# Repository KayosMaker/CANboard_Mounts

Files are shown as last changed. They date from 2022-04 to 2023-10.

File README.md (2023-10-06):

# Mounting Solutions for Nema 14 Based CANbus Toolhead Boards
Files are available to support the following boards:
* BTT EBB36 CAN v1.0
* BTT EBB36 CAN v1.1
* BTT EBB36 CAN v1.2
* Mellow FLY SHT-36
* Mellow FLY SHT-36 2.0

The EBB36 1.0 had rear facing buttons that necessitated a more complicated mount to retain functionality.  Those mounts are in a dedicated folder.  (Note: I won't be updating the mounts for this board to include additional extruders, since it has been superceded by v1.1 and v1.2)  

The EBB36 v1.1, EBB36 v1.2, Mellow Fly SHT-36, and Mellow FLY SHT-36 v2.0 all use the same set of mounts.  They are in a dedicated folder.

## Extruder Compatibility
Since each extruder using a NEMA 14 seems to use it's own unique motor orientation, I created this set of mounts to cover most common setups.  These mounts allow the board to be oriented properly with the umbilical strain relief pointing up, despite the different motor orientations.  If there's a common extruder with a different motor orientation that I missed, just message me on Discord or open an issue here on Git to let me know.  The current files align with the motor orientations of the following extruders: 
* Sherpa Mini
* Sherpa Micro
* LGX Lite
* Sailfin (OG Sailfin as well as my silly Sharkfin mod)
* Orbiter v1.5
* Orbiter v2.0
* VZHextrudort High
* VZHextrudort Low
* VZHextrudort CNC
* Galileo 2 Standalone(works with Orbiter v2 mounts)
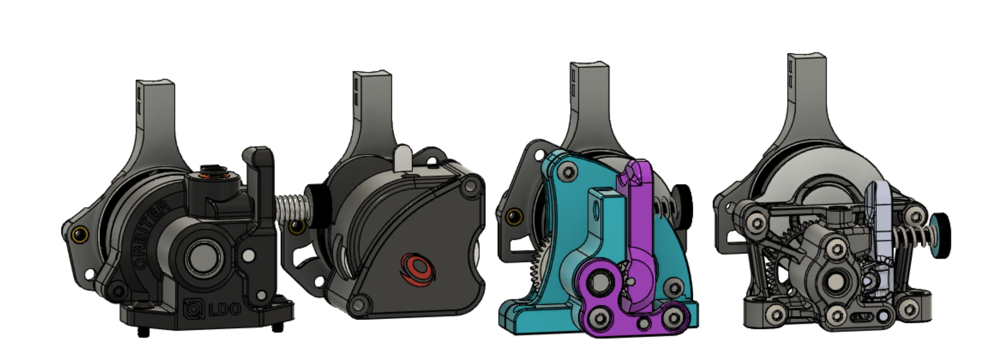
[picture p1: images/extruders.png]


## Plate Types
There are 3 types of plates available: plain, strain relief, and overmold strain relief.  Each has a dedicated folder for the related stls.  The basic strain relief is for most diy cables.  The overmold strain relief is for retail cables available from Molex.  The plain brackets are for printers that have their own solution for umbilical or cable chains. 

Mellow has moved to a new dual plug setup on the FLY SHT-36 2.0, negating the use of the overmold brackets.  Stick with the regular strain relief versions for that board.

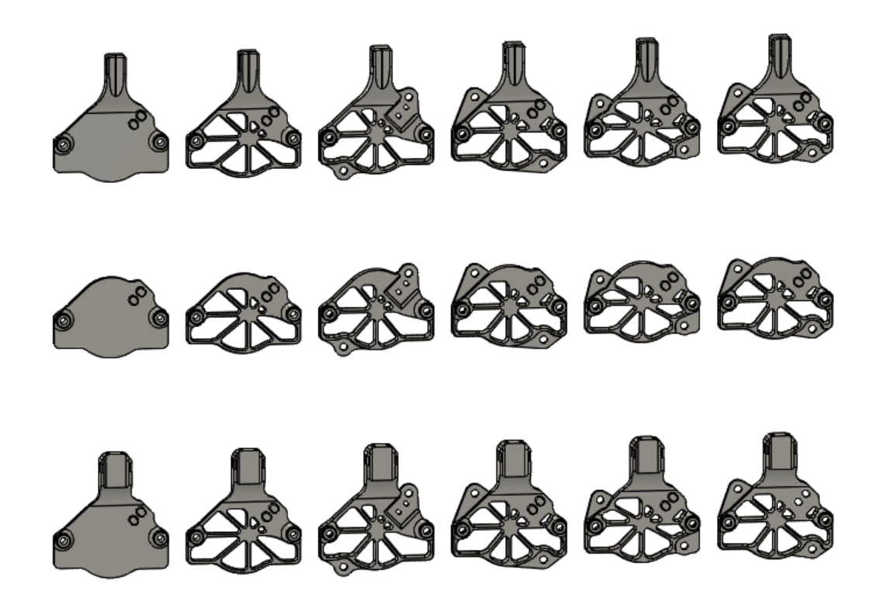
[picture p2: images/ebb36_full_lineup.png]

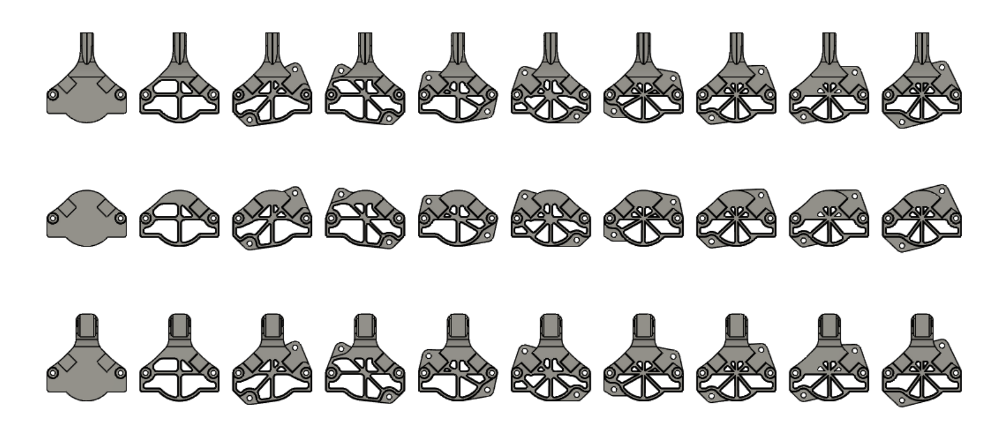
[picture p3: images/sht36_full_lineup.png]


## Usage Notes
The output for the stepper can be switched to the other side of the board if the user wants it so.  The bracket base geometries have clearance for that in regular and mirrored orientations.  Not all extruder motor orientations allow this, but some do.
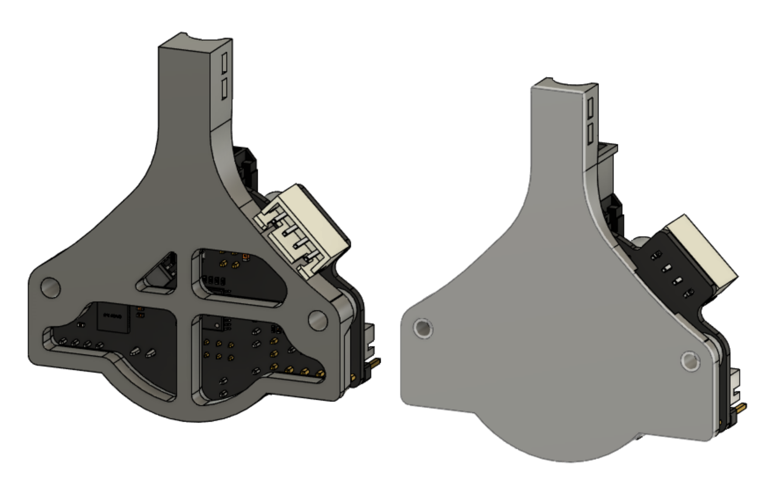
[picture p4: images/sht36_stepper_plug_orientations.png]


These plates are meant to work with printed mounting posts as spacers.  The extruder motor gets mounted with screws that are 5mm longer than called for(so they protrude from the back of the motor mounting ears).  Each end of the printed standoff post gets an M3 heatset insert.  Mounting post length should be chosen based on the motor you are using.  Measure the distance from the back of the motor to the back side of the mounting ears.  Add .5-1mm so the board mount isnt touching the motor, and print the corresponding post length from the folder.  The post is screwed onto the protruding motor mounting screw, and then the mounting bracket is screwed into the mounting posts.  Then you mount the board on the bracket.  The brackets with different board and motor screw orientations will require heatsets in the bracket, to mount the board. 

There are 3 styles of standoff posts available.  They print in the orientation shown.  The classic round ones are fine as long as you print hot enough that layer adhesion is strong.  Geometry is in place to allow the internal overhang to print easily.  If that makes you uneasy, choose the octagonal or teardrop shapes and print them lying down as shown.  
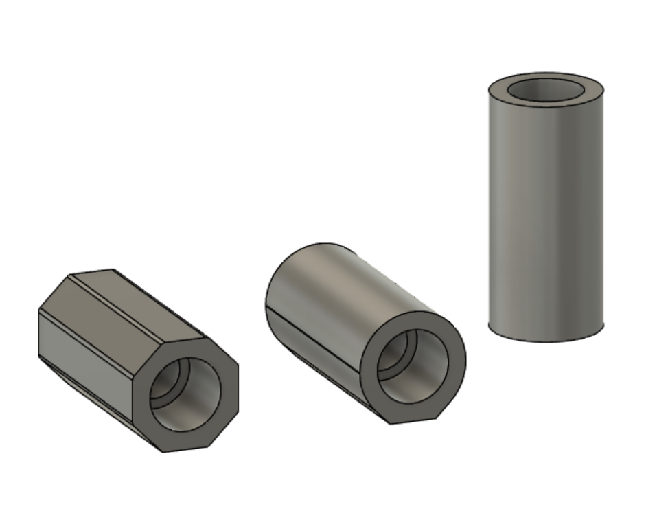
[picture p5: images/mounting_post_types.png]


## Usermods
Mod|Description|Link
|:--------:|:-------------------------:|:---:|
Reapola's Galileo Mounts|Mounts for rear or side of Galileo, with CAD|https://github.com/KayosMaker/CANboard_Mounts/tree/main/Usermods/Reapola/Galileo%20Mount%20for%20SHT36
K78L12-500R3 Mounts|Mounts with K78L12-500R3 included, with CAD|https://github.com/KayosMaker/CANboard_Mounts/tree/main/Usermods/mk-maddin/K78l12-500R3_24-12V_mount

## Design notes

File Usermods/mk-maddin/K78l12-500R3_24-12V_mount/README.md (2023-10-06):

# Description
This mod additionally mounts the 24V-12V [K78L12-500R3](https://www.digikey.com/en/products/detail/mornsun-america-llc/K78L12-500R3/16784476) buck converter.
This is helpful when using e.g. 12V fans like Delta BFB0412HHA-A (12V) on your toolhead.

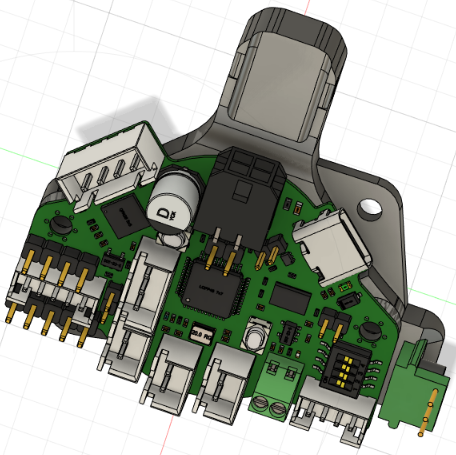
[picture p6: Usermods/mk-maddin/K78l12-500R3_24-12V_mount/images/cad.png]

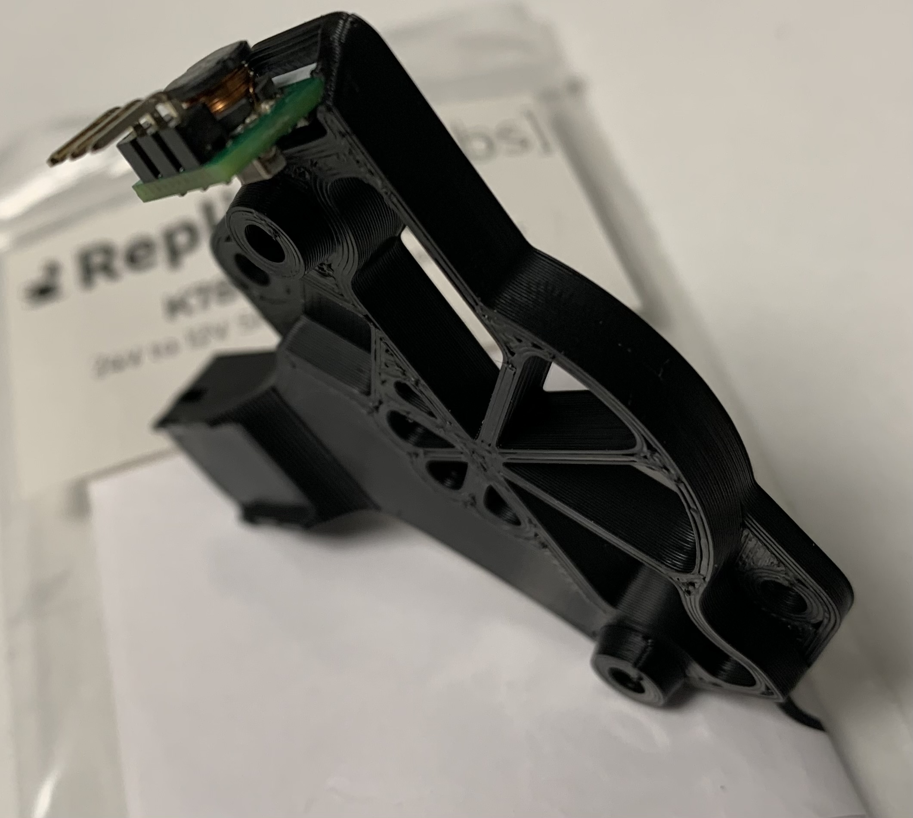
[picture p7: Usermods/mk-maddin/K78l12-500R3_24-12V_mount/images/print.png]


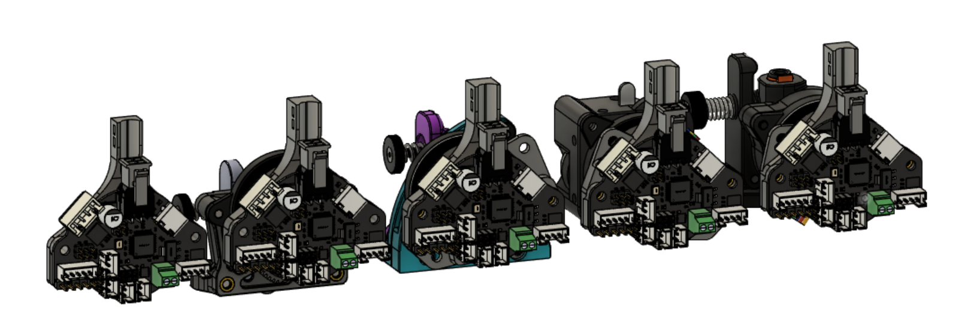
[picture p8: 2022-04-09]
images/sht36_lineup_w_boards.png

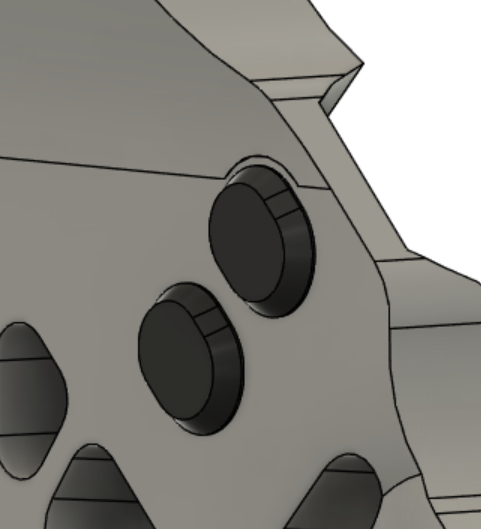
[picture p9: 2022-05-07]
images/ebb36_buttons_front.png

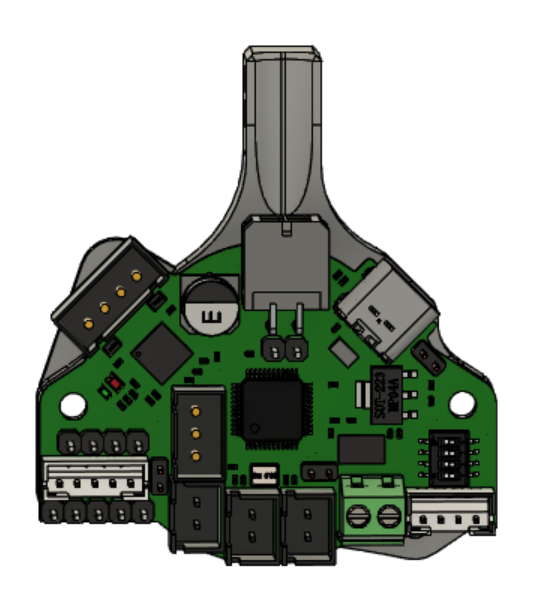
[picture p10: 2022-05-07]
images/ebb36_bracket.png

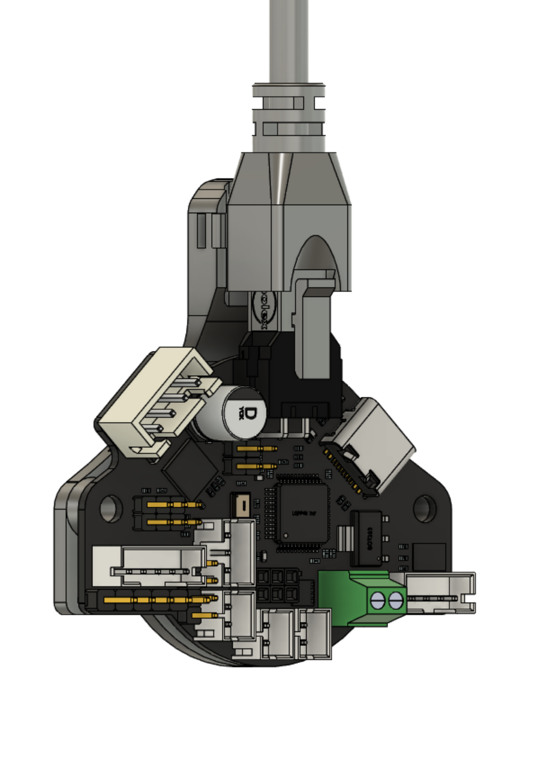
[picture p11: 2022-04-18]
images/overmolded_strain_relief.png

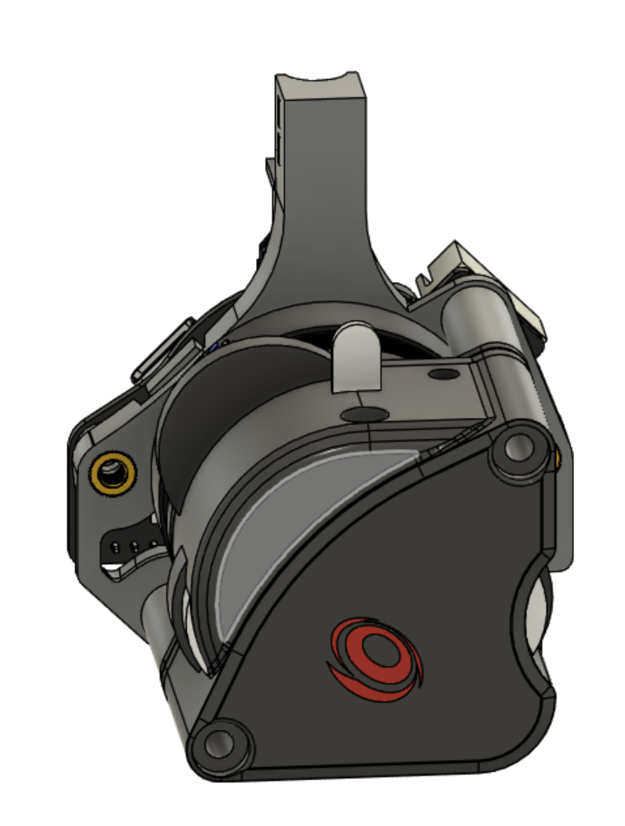
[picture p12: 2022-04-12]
images/sht36_complete_front.png

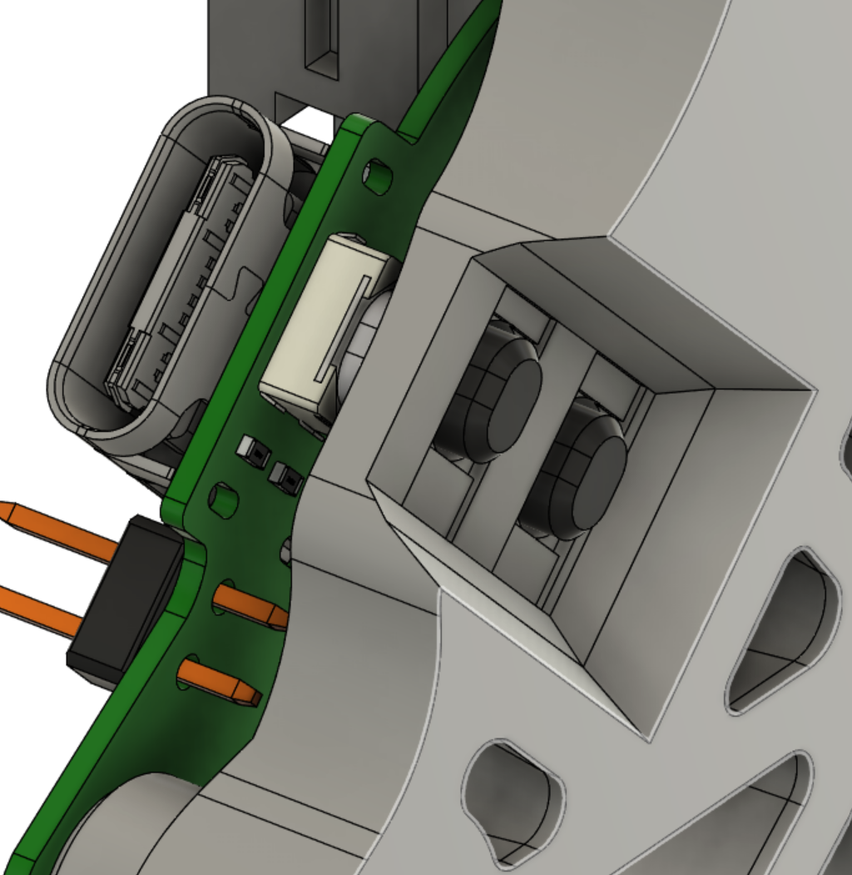
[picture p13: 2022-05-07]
images/ebb36_buttons_rear.png

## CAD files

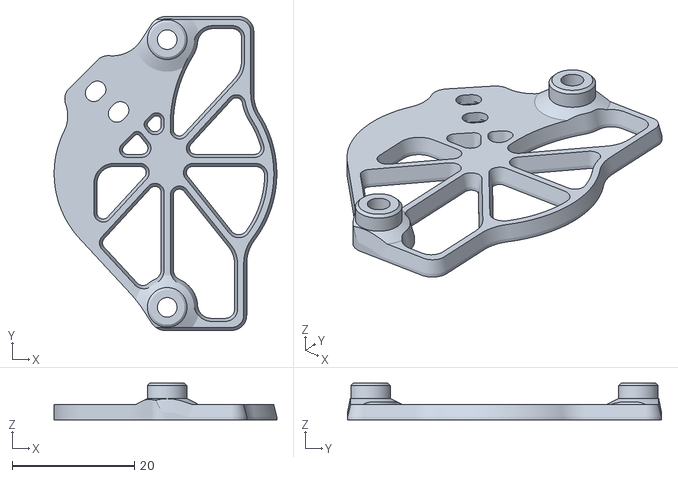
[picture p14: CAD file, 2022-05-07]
STLs/BTT_EBB36_1.0_Mounts/BTT_EBB36_1.0_mounts_plain/EBB36 1.0 sherpa mini mount.stl
36.5 x 51.4 x 6.00

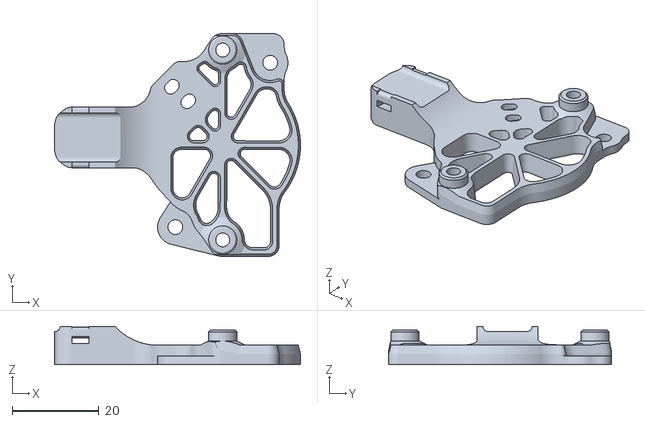
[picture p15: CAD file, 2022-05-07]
STLs/BTT_EBB36_1.0_Mounts/BTT_EBB36_1.0_mounts_with_overmold_strain_relief/EBB36 1.0 orbiter 2.0 mount overmold strain relief.stl
56.8 x 51.4 x 8.86

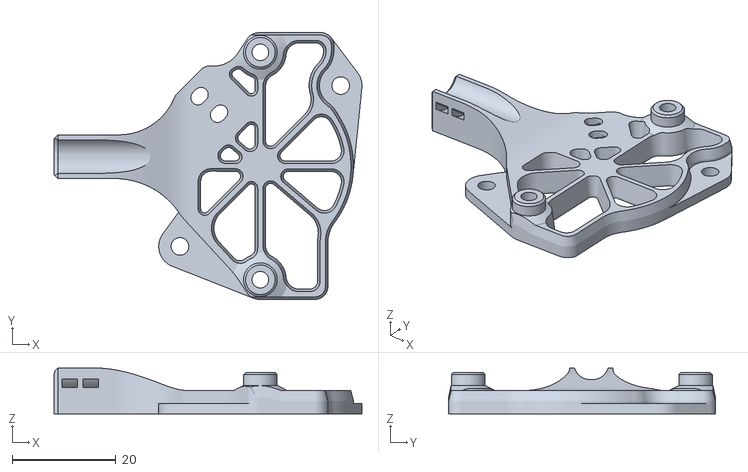
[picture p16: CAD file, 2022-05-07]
STLs/BTT_EBB36_1.0_Mounts/BTT_EBB36_1.0_mounts_with_strain_relief/EBB36 1.0 lgx lite mount strain relief.stl
59.4 x 51.4 x 8.86

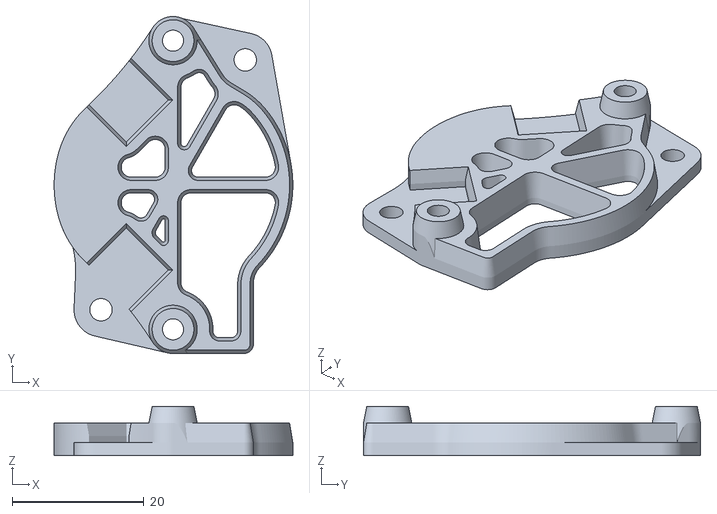
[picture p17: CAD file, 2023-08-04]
STLs/Mellow_SHT36_BTT_EBB36_1.1_1.2_Mounts/Mellow_SHT36_and_BTT_EBB36_1.1_1.2_mounts_plain/STH-36_and_BTT_EBB36_1.1_1.2_orbiter_2.0_mounting_plate.stl
36.3 x 51.2 x 7.50

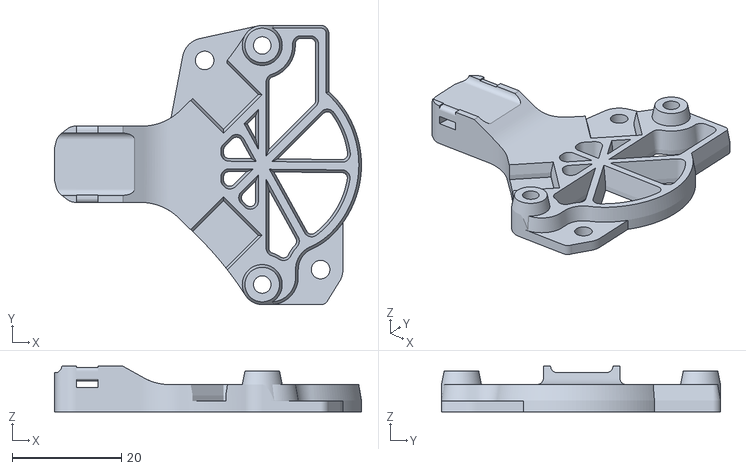
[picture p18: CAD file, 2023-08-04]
STLs/Mellow_SHT36_BTT_EBB36_1.1_1.2_Mounts/Mellow_SHT36_and_BTT_EBB36_1.1_1.2_mounts_with_overmold_strain_relief/SHT-36_and_BTT_EBB3_vzhextrudort_high_mounting_plate_overmold_strain.stl
56.3 x 51.2 x 8.36

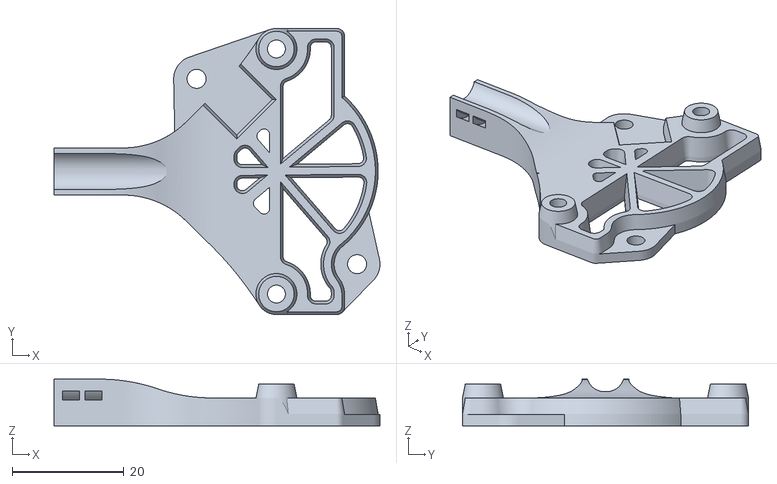
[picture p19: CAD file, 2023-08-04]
STLs/Mellow_SHT36_BTT_EBB36_1.1_1.2_Mounts/Mellow_SHT36_and_BTT_EBB36_1.1_1.2_mounts_with_strain_relief/SHT-36_and_BTT_EBB36_1.1_1.2_vzhextrudort_cnc_mounting_plate_strain_relief.stl
58.3 x 51.2 x 8.36

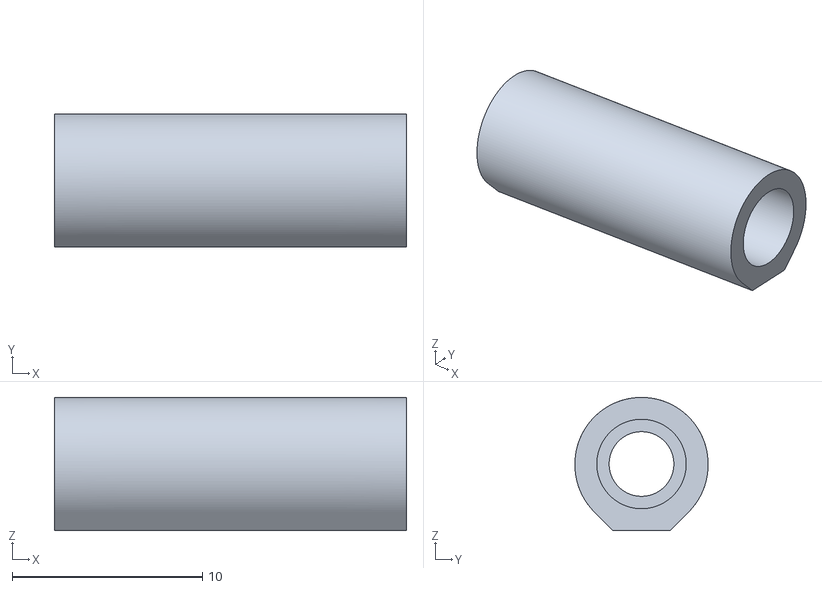
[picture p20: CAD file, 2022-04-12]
STLs/motor_standoff_posts/18.5mm_teardrop_universal_spacer.stl
18.5 x 7.00 x 7.00

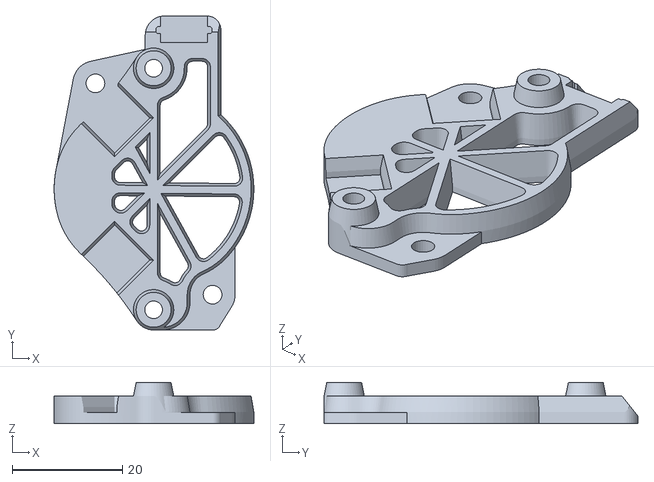
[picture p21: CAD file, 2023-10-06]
Usermods/mk-maddin/K78l12-500R3_24-12V_mount/STL/Mellow_SHT36_BTT_EBB36_1.1_1.2_Mount/Mellow_SHT36_and_BTT_EBB36_1.1_1.2_mounts_plain/SHT-36_vzhextrudort_high_mounting_plate_K78l12-500R3.stl
36.3 x 57.0 x 7.50

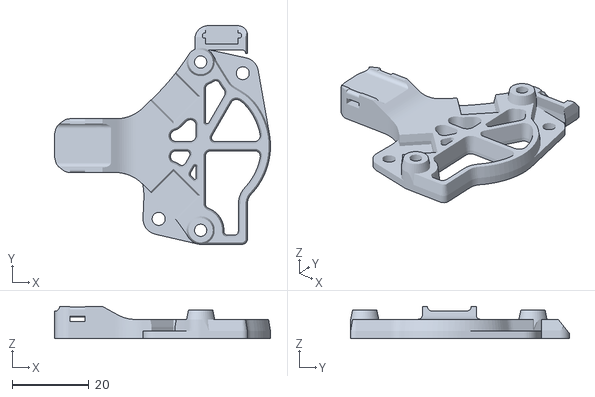
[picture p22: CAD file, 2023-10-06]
Usermods/mk-maddin/K78l12-500R3_24-12V_mount/STL/Mellow_SHT36_BTT_EBB36_1.1_1.2_Mount/Mellow_SHT36_and_BTT_EBB36_1.1_1.2_mounts_with_overmold_strain_relief/STH-36_orbiter_2.0_mounting_plate_overmold_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
56.3 x 57.0 x 8.36

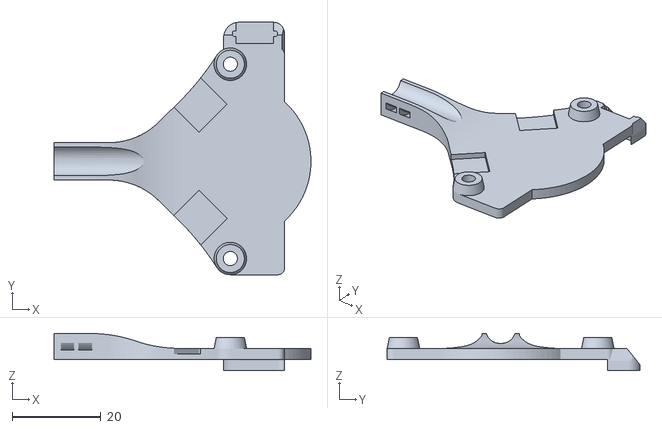
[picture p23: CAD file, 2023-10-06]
Usermods/mk-maddin/K78l12-500R3_24-12V_mount/STL/Mellow_SHT36_BTT_EBB36_1.1_1.2_Mount/Mellow_SHT36_and_BTT_EBB36_1.1_1.2_mounts_with_strain_relief/STH-36_basic_geometry_mounting_plate_strain_relief_K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
58.0 x 57.0 x 8.36

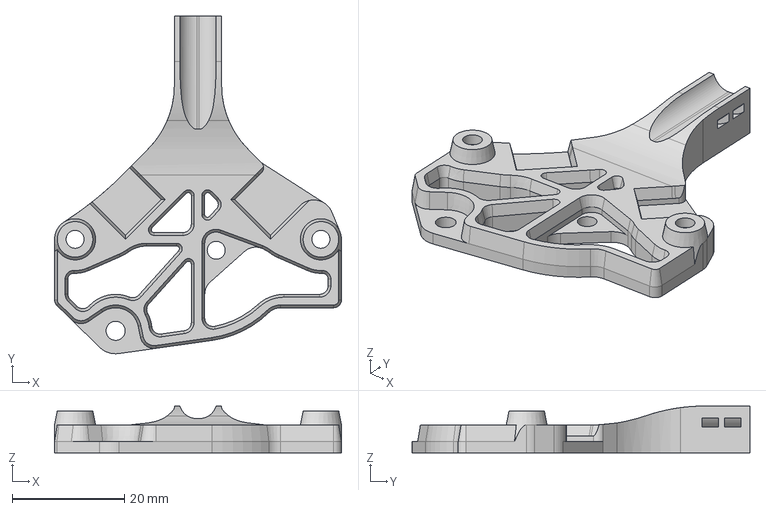
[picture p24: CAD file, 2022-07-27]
Usermods/Reapola/Galileo Mount for SHT36/CAD/sht36_galileo_side_STH-36_v5.step
51.2 x 60.2 x 8.36 mm

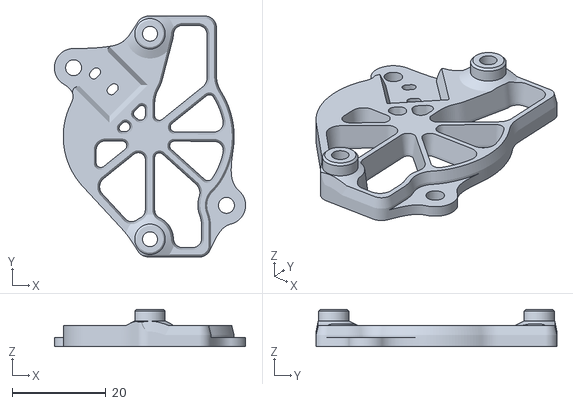
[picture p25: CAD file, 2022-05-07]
STLs/BTT_EBB36_1.0_Mounts/BTT_EBB36_1.0_mounts_plain/EBB36 1.0 sailfin mount.stl
40.8 x 51.4 x 8.00

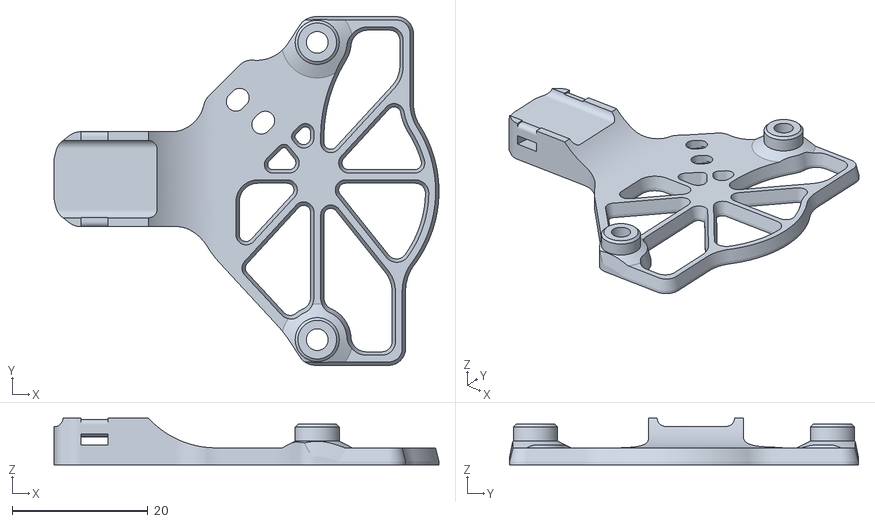
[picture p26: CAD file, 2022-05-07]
STLs/BTT_EBB36_1.0_Mounts/BTT_EBB36_1.0_mounts_with_overmold_strain_relief/EBB36 1.0 sherpa mini mount overmold strain relief.stl
56.8 x 51.4 x 6.86

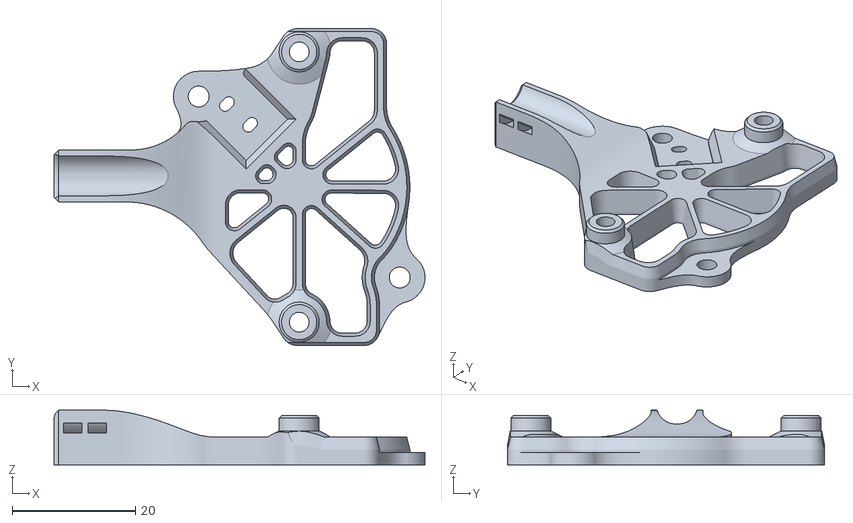
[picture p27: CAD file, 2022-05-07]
STLs/BTT_EBB36_1.0_Mounts/BTT_EBB36_1.0_mounts_with_strain_relief/EBB36 1.0 sailfin mount strain relief.stl
60.2 x 51.4 x 8.86

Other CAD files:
STLs/Mellow_SHT36_BTT_EBB36_1.1_1.2_Mounts/Mellow_SHT36_and_BTT_EBB36_1.1_1.2_mounts_plain/SHT-36_and_BTT_EBB36_1.1_1.2_vzhextrudort_cnc_mounting_plate.stl
STLs/Mellow_SHT36_BTT_EBB36_1.1_1.2_Mounts/Mellow_SHT36_and_BTT_EBB36_1.1_1.2_mounts_with_overmold_strain_relief/STH-36_and_BTT_EBB36_1.1_1.2_sailfin_mounting_plate_overmold_strain.stl
STLs/Mellow_SHT36_BTT_EBB36_1.1_1.2_Mounts/Mellow_SHT36_and_BTT_EBB36_1.1_1.2_mounts_with_strain_relief/STH-36_and_BTT_EBB36_1.1_1.2_orbiter_2.0_mounting_plate_strain_relief.stl
STLs/motor_standoff_posts/18.5mm_round_universal_spacer.stl
STLs/BTT_EBB36_1.0_Mounts/BTT_EBB36_1.0_mounts_plain/EBB36 1.0 lgx lite mount.stl
STLs/BTT_EBB36_1.0_Mounts/BTT_EBB36_1.0_mounts_plain/EBB36 1.0 orbiter 1.5 mount.stl
STLs/BTT_EBB36_1.0_Mounts/BTT_EBB36_1.0_mounts_plain/EBB36 1.0 orbiter 2.0 mount.stl
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

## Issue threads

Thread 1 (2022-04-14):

Orbiter v1.5

jihunpark26, 2022-04-14:
The direction of rotation is not vertical
![Uploading 29FDD2B0-E2FA-4931-849A-98316C9B7963.jpeg…]()

KayosMaker, 2022-04-15:
the orbiter plate is for orbiter 2.0
i am making a new one for orbiter 1.5
they have different motor rotation

KayosMaker, 2022-04-15:
added files for orbiter 1.5, including cad
closing

Closed 2022-04-15.

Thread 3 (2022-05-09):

SHT-36 mount for Galileo

fuzzynm, 2022-05-09:
Would it be possible for you to model one up for the Galileo?  The SailFin is close but the motor mounts are off by a few degrees for the Galileo.

https://github.com/JaredC01/Galileo

Tuerlich86, 2022-07-01:
Yes, that were very nice!!!

KayosMaker, 2023-04-30:
REapola made one, its in a usermod folder now.

Closed 2023-04-30.

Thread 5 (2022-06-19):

Fly sht 42 support

talrhv, 2022-06-19:
Hi! Thanks for your work.
Can you make one also for fly sht42?
Thank you!

KayosMaker, 2023-04-30:
Sorry I have no plans to develop mounts for that particular board.

Closed 2023-04-30.

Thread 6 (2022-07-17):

BTT EBB36 V1.1 & V1.2 support, works with SHT 36 mount

sneakytreesnake, 2022-07-17:
Tested the EBB36 V1.1 with the SHT36 mount and it works great! Worth clarifying in the mod description.

brunnels, 2022-09-26:
Yes, seems okay.  Buttons are on the front now so button access on back no longer necessary.

KayosMaker, 2023-04-30:
Thanks y'all.  Finally updating the repo now.

Closed 2023-04-30.

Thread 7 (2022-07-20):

Input shaper orientations

CircuitSetup, 2022-07-20:
"Klipper does not to my knowledge currently support input shaper tuning in other orientations"

FYI, this can be done by using `axes_map` under [adxl345]. [See here.](https://www.klipper3d.org/Config_Reference.html#adxl345)

AndyHegemann, 2022-09-15:
The axes_map does allow you to use an adxl345 in other orientations, but only ones that align its' axes with those of movement.

This doesn't let you mount the board to a sailfin or orbiter motor like with a sherpa mini.

Here is the blurb explaining axes_map from the kilpper docs:

#axes_map: x, y, z
#   The accelerometer axis for each of the printer's X, Y, and Z axes.
#   This may be useful if the accelerometer is mounted in an
#   orientation that does not match the printer orientation. For
#   example, one could set this to "y, x, z" to swap the X and Y axes.
#   It is also possible to negate an axis if the accelerometer
#   direction is reversed (eg, "x, z, -y"). The default is "x, y, z".

pottedplant, 2023-01-11:
`axes_map` would not help. Nonetheless the orientation does not matter for input shaper as it does not look at a specific axis from the sensor but takes the input from all 3 axis. So no need to align your axis for IS to work properly.

https://github.com/Klipper3d/klipper/pull/5979#issuecomment-1379486909

Closed 2023-04-30.

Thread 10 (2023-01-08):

Mount option for CW2?

ressu, 2023-01-08:
It seems that this repo comes highly recommended on many Voron community resources, but the one thing that is missing from the mounts is a mount for [Clockwork2](https://github.com/VoronDesign/Voron-Stealthburner). There is a slighly modified mount floating in Voron Discord that is modified from LGX lite.

Would it be possible to get CW2 versions of the mounts here too?

KayosMaker, 2023-04-30:
I decided to leave it to Voron to develop mounts for the stock toolheads.  My mounts are primarily to help folks running non standard setups.

Closed 2023-04-30.

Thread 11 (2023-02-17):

Missing stls for standoffs

flow23, 2023-02-17:
I can't find the stls for the standoffs.

KayosMaker, 2023-04-30:
In the STL folder, the standoffs have their own folder.

Closed 2023-04-30.

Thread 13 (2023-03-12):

Mount option for Vz-Hextrudort-Low

ivanroberto, 2023-03-12:
Hello, it would be great if you had support for the Vz-Hextrudort-Low extruder.
[https://github.com/VzBoT3D/Vz-HextrudORT](url)
If any existing extruders are compatible, please let me know.
Thanks

KayosMaker, 2023-04-30:
I'm looking at things today for the vz-hgextrudort series.  I'll update the repo info when i know what works or have new stls to add.

KayosMaker, 2023-05-02:
Im closing this issue for now.  Use the LGX Lite mount mirrored on X for the VZ HextrudORT Low extruders.  It's close enough to get you though til i can create perfect mounts for the VZ extruders.

KayosMaker, 2023-06-09:
Not sure if this will notify you, but if it does, I've added native mounts for VZHextrudort now.

Closed 2023-05-02.

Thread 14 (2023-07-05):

vzhextrudort_low_mounting_plate_strain_relief missing heatset inserts

rypaw, 2023-07-05:
SHT-36_and_BTT_EBB36_1.1_1.2_vzhextrudort_low_mounting_plate_strain_relief STL file is missing the heat set insert modifications on the bracket

KayosMaker, 2023-07-05:
thanks ill look at that later today and push an update!

claytono, 2023-08-02:
Looks like the Sherpa Micro strain relief STL is also missing heatset inserts

KayosMaker, 2023-08-04:
just finished fixing all the missing heatset countersinks.  sorry bout that yall.  pushing update momentarily so closing this now

Closed 2023-08-04.

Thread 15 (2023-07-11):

Sherpa crew mini support

wight554, 2023-07-11:
Sherpa mount ~~might work~~ (edit. won't work), but would be great to separate mount with matching silhouette
https://github.com/jrlomas/Sherpa-Crew-Mini
Thanks for your work!

KayosMaker, 2023-08-04:
That thing is pretty awesome, but I think i'll have to pass on including it in the lineup of mounts.  I just dont have time at present to work something up.  you could drop the sherpa crew cad into the step file from my repo and see if it lines up with any of the other extruders with diagonally oriented motors.  you might find one close enough to work.  you may need to mirror the bracket on X, but my parts are designed to be able to do that.  I hope you figure something out.  if you use my geometry to design a new bracket, post it in a usermod folder and ill approve the commit.  closing this issue.

Closed 2023-08-04.

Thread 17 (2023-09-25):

Extruder from IdeaFormer Driect Drive Extruder

bvitl, 2023-09-25:
You can create mount for extruder:
https://grabcad.com/library/ideaformer-bde-extruder-1

Thank you.

KayosMaker, 2023-09-25:
I took a look at the extruder in CAD.  I'm not very impressed, so I don't plan on making a dedicated mount.  It does a very poor job of restraining the filament path.  I'd recommend going with a Sherpa Mini, Sharkfin, or other BMG based extruder, if thats the path you want to go down.
I did measure the motor angle of the Ideaformer BDE.  It does not perfectly align with any of my other mounts, but it is within 0.5 degrees of a mirrored Orbiter 1.5 mount.  If you mirror the Orbiter 1.5 mount on X, it will work with the Ideaformer extruder.
Closing the issue now.  Thanks!

Closed 2023-09-25.

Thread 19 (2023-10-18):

SUGGESTION: print settings

MartijnGevaert, 2023-10-18:
Hey Kayos, great repo, small suggestion, it might be valuable to add in some print instructions, such as recommending ABS or other high temp material, and also print settings such as perimeters required infill...
Could either save a couple of grams, or save someone from a melted mount.

Thanks for sharing all this work!

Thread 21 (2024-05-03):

Sherpa Micro is listed but has no STL

Altirix, 2024-05-03:
Sherpa Micro is listed as supported but no STL explicitly states it is intended for this extruder.

https://github.com/KayosMaker/CANboard_Mounts/issues/8 is closed and there is no info on what stl should be used either.

testing the sailfin mount its maybe 3 degrees off to the right, no other mounts have a similar mounting pattern.

This seems to be due to the fact the sailfin mount doesn't factor in the top motor screw has a range of positions depending on how tight the motor meshes to the pom gear.

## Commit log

2022-04-09 init commit
    [STH-36_lgx_lite_mounting_plate.stl, STH-36_lgx_lite_mounting_plate_strain_relief.stl, STH-36_orbiter_mounting_plate.stl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]
2022-04-12 add spacer stls
    [14.0mm_hex_universal_spacer.stl, 14.0mm_round_universal_spacer.stl, 14.0mm_teardrop_universal_spacer.stl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]
2022-04-12 add more mounting post lengths
    [18.5mm_hex_universal_spacer.stl, 18.5mm_round_universal_spacer.stl, 18.5mm_teardrop_universal_spacer.stl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]
2022-04-15 add orbiter v1.5 plates and update cad
    [STH-36_orbiter_1.5_mounting_plate.stl, STH-36_orbiter_1.5_mounting_plate_strain_relief.stl, STH-36_orbiter_2.0_mounting_plate.stl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]
2022-04-18 add overmolded option
    add stls for overmolded plug strain relief
    update cad
    update images
    [STH-36_lgx_lite_plate_overmold_strain.stl, STH-36_orbiter_1.5_mounting_plate_overmold_strain.stl, STH-36_orbiter_2.0_mounting_plate_overmold_strain.stl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]
2022-05-07 add btt ebb36 mounts
    [14.0mm_hex_universal_spacer.stl, 14.0mm_round_universal_spacer.stl, 14.0mm_teardrop_universal_spacer.stl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]
2022-06-03 Rename all mentions of hex into oct
    [14.0mm_oct_universal_spacer.stl, 14.5mm_oct_universal_spacer.stl, 15.0mm_oct_universal_spacer.stl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]
2022-07-27 add Reapola's galileo mounts
    [sht36_galileo_rear_v4.step, sht36_galileo_rear_v4.stl, sht36_galileo_side_STH-36_v5.step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]
2023-05-02 rename files
    rename to accommodate new board versions so it isnt confusifying
    [EBB36 1.0 lgx lite mount overmold strain relief.stl, EBB36 1.0 lgx lite mount strain relief.stl, EBB36 1.0 lgx lite mount.stl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]
2023-06-09 add new mounts
    mounts for:
    -vzhextrudort low, high, cnc
    -sherpa micro
    [SHT-36_and_BTT_EBB36_1.1_1.2_sherpa_micro_mounting_plate.stl, SHT-36_and_BTT_EBB36_1.1_1.2_sherpa_micro_mounting_plate_strain_relief.stl, SHT-36_and_BTT_EBB36_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]
2023-08-04 add missing heatsert countersinks to recent bracket additions
    -added heatsert countersinks to the vzhextrudort and sherpa micro brackets
    -updated all heatsert countersinks to bridged type design for best printing
    -update cad
    [SHT-36_and_BTT_EBB36_1.1_1.2_sherpa_micro_mounting_plate.stl, SHT-36_and_BTT_EBB36_1.1_1.2_sherpa_micro_mounting_plate_strain_relief.stl, SHT-36_and_BTT_EBB36_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]
2023-10-05 Mount for K78L12-500R3
    [SHT-36_sherpa_micro_mounting_plate_K78l12-500R3.stl, SHT-36_sherpa_micro_mounting_plate_overmold_strain_K78l12-500R3.stl, SHT-36_sherpa_micro_mounting_plate_st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]
